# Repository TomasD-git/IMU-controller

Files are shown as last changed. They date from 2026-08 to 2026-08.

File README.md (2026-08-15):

# IMU controller  
### **Ultra low power IMU controller, can control anything over bluetooth using IMU, all running on coin cell CR2032 battery**  



## Features:  
- **Ultra low power 11.5uA power consumption in sleep mode**  
- **Most power consumption(LED on max brightness, cpu and ram fully active, BLE active, IMU running) 16.5mA**
- **Battery lasts 700ish days(11.1µA consumption on a 220mah battery)**
- **Powerfull BLE 5.3 with antenna**
- **NRF52810 as MCU**
- **BMI270 as IMU**
- **CR2032 battery**
- **Red LED**

<details>
<summary>How to does it work</summary>

## The button enables/disables the BLE  
## The LED indicates if BLE is active (LED flashes once = BLE on, LED flashes twice = BLE off)  
## All components are in deep sleep until accel detects movement  
## After few seconds of inactivity goes back to deep sleep  

</details>

<details>
<summary>How to flash</summary>

0. **Connect device to PC using segger j-link**   
1. **Open VS Code**  
2. **Select connected device in left bottom corner:** 


4. **Flash:**  
    

( For Debugging select: )  
  

</details>

<details>
<summary><strong>Power consumption</strong></summary>

## Deep Sleep:
| Component | What's active | Consumption |
|---|---|---|
| NRF52810 | Deep Sleep | 1.1µA |
| BMI270 | Accel-only Low power mode | 10µA |
| LED | Off | 0µA |
| Total | | 11.1µA |
| Battery life | 220,000µAh ÷ 11.1µA | ~825 days (~2.3 years) |
 
## Deep Sleep + slow BLE:
| Component | What's active | Consumption |
|---|---|---|
| NRF52810 | BLE with  4000ms interval (just to hold connections) | 6.4µA |
| BMI270 | Accel-only Low power mode | 10µA |
| LED | Off | 0µA |
| Total | | 16.4µA |
| Battery life | 220,000µAh ÷ 16.4µA | ~559 days (~1.53 years) |
 
## Fully active:
| Component | What's active | Consumption |
|---|---|---|
| NRF52810 | BLE with 7.5ms interval, CPU active | 13.8mA |
| BMI270 | Normal mode | 0.685mA |
| LED | On | 2.0mA |
| Total | | 16.485mA |
| Battery life | 220,000µAh ÷ 16.485mA | ~13.3 hours |

> **Can last less depending on quality of the Battery**  

</details>

<details>
<summary>How to Assemble</summary>

1. **Print all parts and assemble PCB**  
2. **Flash**  
3. **Place the Coin Cell battery into the holder**  
4. **Place the PCB inside the case**  
5. **Screw the bottom lid into the top one**  
6. **Verify it works by clicking the button**  

</details>

<details>  
<summary>Pictures</summary>  
  








</details>  

<details>
<summary>BOM</summary>

|Name |Purpose |Quantity  |Total Cost (USD)|Link |Distributor|
|---|---|---|---|---|---|
|PCB + stencil |all components are on this |1 |13.97 |https://jlcpcb.com |jlcpcb |
|ALL components|all components that are on pcb |1 |38.87 |https://lcsc.com |lcsc |
|CR2032 |battery which poweres the entire PCB |1 |4 | |local store|
|SEGGER J-Link |Flashes the NRF board with firmware |1 |4.94 |https://www.aliexpress.com/item/1005005802567589.html |Aliexpress |
|EU tarrifs |3 EU for each category for orders under 150 eu|3 |32.66 |https://commission.europa.eu/news-and-media/news/ensuring-fairness-and-safety-eur3-customs-duty-low-value-parcels-2026-06-29_en|EU |
| | |Total cost|94.44 | | |
| |If outside EU |Total cost|61.78 | | |

</details>

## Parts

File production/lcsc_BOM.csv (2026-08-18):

LCSC BOM.csv |  |  |  |  |  |  |  |  |  | LCSC BOM Quotation
 |  |  |  |  |  |  |  |  |  | BOM Date Created?18/08/26 19:02:04 |  |  |  | BOM Export Date: 18/08/26 19:03:08 |  |  |  | The matching result is a real-time query result, availability and prices may fluctuate. Backorder items are estimated prices for your reference, please submit "Create Quote" to get the real price. All information is provided "as is" and is subject to change without notice. Any use made of the information provided is without recourse to LCSC and at the user's risk.
 |  |  |  |  |  |  |  |  |  | EST TOTAL :$28.13 |  |  |  | Website?https://www.lcsc.com/bom
Uploaded data |  |  |  |  |  |  |  |  |  | LCSC Matching Results
LCSC# | Mfr. | Mrf# | Description | Package | Value | Customer Part Number | Quantity | Target Price(USD) | Target Lead Time(Business Days) | Mrf# | Mfr. | Order Qty. | Unit Price(USD) | Ext.Price(USD) | LCSC# | Package | Min | Mult | SPQ | Availability | Stock Status | Customer Notes | Description | Matched status | Product Link
C964833 |  |  | MY-2032-12 | BAT-SMD_MY-2032-12 |  | - | 5 |  |  | MY-2032-12 | MYOUNG | 5 | 0.0940 | 0.47 | C964833 | - | 5 | 5 | 1500 | 17040 | In Stock |  | Battery Clip Coin CR2032 Cell SMD | Exact Matches | https://www.lcsc.com/product-detail/C964833.html
C60474 |  |  | 100nF | 402 |  | - | 100 |  |  | CC0402KRX7R7BB104 | YAGEO | 100 | 0.0057 | 0.57 | C60474 | 0402 | 100 | 100 | 10000 | 4786700 | In Stock |  | 100nF ±10% 16V Ceramic Capacitor X7R 0402 | Exact Matches | https://www.lcsc.com/product-detail/C60474.html
C106201 |  |  | 12pF | 402 |  | - | 100 |  |  | CC0402JRNPO9BN120 | YAGEO | 100 | 0.0038 | 0.38 | C106201 | 0402 | 100 | 100 | 10000 | 1991400 | In Stock |  | 12pF ±5% 50V Ceramic Capacitor NP0 0402 | Exact Matches | https://www.lcsc.com/product-detail/C106201.html
C15850 |  |  | 10uF | 805 |  | - | 20 |  |  | CL21A106KAYNNNE | Samsung Electro-Mechanics | 20 | 0.0994 | 1.99 | C15850 | 0805 | 20 | 20 | 2000 | 3004120 | In Stock |  | 10uF ±10% 25V Ceramic Capacitor X5R 0805 | Exact Matches | https://www.lcsc.com/product-detail/C15850.html
C29936 |  |  | 0.8pF | 402 |  | - | 50 |  |  | CL10B105KA8NNNC | Samsung Electro-Mechanics | 50 | 0.0226 | 1.13 | C29936 | 0603 | 50 | 50 | 4000 | 2688800 | In Stock |  | 1uF ±10% 25V Ceramic Capacitor X7R 0603 | Exact Matches | https://www.lcsc.com/product-detail/C29936.html
C88902 |  |  | 4.7uF | 603 |  | - | 20 |  |  | GJM1555C1HR80WB01D | muRata | 20 | 0.0404 | 0.81 | C88902 | 0402 | 20 | 20 | 10000 | 187660 | In Stock |  | 0.8pF 50V Ceramic Capacitor C0G 0402 | Exact Matches | https://www.lcsc.com/product-detail/C88902.html
C19666 |  |  | 1.2pF | 402 |  | - | 10 |  |  | CL10A475KO8NNNC | Samsung Electro-Mechanics | 10 | 0.0336 | 0.34 | C19666 | 0603 | 10 | 10 | 4000 | 2943250 | In Stock |  | 4.7uF ±10% 16V Ceramic Capacitor X5R 0603 | Exact Matches | https://www.lcsc.com/product-detail/C19666.html
C1551 |  |  | 100pF | 402 |  | - | 100 |  |  | 0402CG1R2C500NT | FH | 100 | 0.0067 | 0.67 | C1551 | 0402 | 100 | 100 | 10000 | 262900 | In Stock |  | 1.2pF 50V Ceramic Capacitor C0G 0402 | Exact Matches | https://www.lcsc.com/product-detail/C1551.html
C26409 |  |  | 1uF | 603 |  | - | 100 |  |  | CL05C101JB5NNNC | Samsung Electro-Mechanics | 100 | 0.0075 | 0.75 | C26409 | 0402 | 100 | 100 | 10000 | 1025100 | In Stock |  | 100pF ±5% 50V Ceramic Capacitor C0G 0402 | Exact Matches | https://www.lcsc.com/product-detail/C26409.html
 |  |  | Conn_01x05 | PinSocket_1x05_P2.00mm_Vertical |  | - | 1 |  |  | - | - | - | - | - | - | - | - | - | - | - | - |  | - | No Matches Found
C98062 |  |  | 3.9nH | 402 |  | - | 20 |  |  | LQW15AN3N9B00D | muRata | 20 | 0.0391 | 0.78 | C98062 | 0402 | 20 | 20 | 10000 | 5760 | In Stock |  | 750mA 3.9nH 70m? Unshielded Inductor 0402 Fixed Inductors RoHS | Exact Matches | https://www.lcsc.com/product-detail/C98062.html
C2916136 |  |  | AN3216-245 | ANT-SMD_L3.2-W1.6-A |  | - | 5 |  |  | AN3216-245 | Rainsun | 5 | 0.1365 | 0.68 | C2916136 | 1206 | 5 | 5 | 3000 | 13935 | In Stock |  | nan | Exact Matches | https://www.lcsc.com/product-detail/C2916136.html
C91239 |  |  | 2.7nH | 402 |  | - | 20 |  |  | LQW15AN2N7B00D | muRata | 20 | 0.0644 | 1.29 | C91239 | 0402 | 20 | 20 | 10000 | 60920 | In Stock |  | 850mA 2.7nH 50m? Unshielded Inductor 0402 Fixed Inductors RoHS | Exact Matches | https://www.lcsc.com/product-detail/C91239.html
C86064 |  |  | 3.3nH | 402 |  | - | 50 |  |  | LQG15HS3N3S02D | muRata | 50 | 0.0195 | 0.98 | C86064 | 0402 | 50 | 50 | 10000 | 80100 | In Stock |  | 800mA 3.3nH 170m? Multilayer inductor 0402 Fixed Inductors RoHS | Exact Matches | https://www.lcsc.com/product-detail/C86064.html
C137695 |  |  | 620 | 603 |  | - | 100 |  |  | RC0603FR-07620RL | YAGEO | 100 | 0.0065 | 0.65 | C137695 | 0603 | 100 | 100 | 5000 | 123600 | In Stock |  | 620? 100mW 75V Thick Film Resistor ±100ppm/? ±1% 0603 Chip Resistor - Surface Mount RoHS | Exact Matches | https://www.lcsc.com/product-detail/C137695.html
C1558383 |  |  | NRF52810-QFAA-R | UQFN-48_L6.0-W6.0-P0.40-BL-EP4.6 |  | - | 2 |  |  | NRF52810-QFAA-T | NORDIC | 2 | 3.1247 | 6.25 | C1558383 | QFN-48-EP(6x6) | 1 | 1 | 490 | 243 | In Stock |  | IC RF TXRX 2400MHz~2483.5MHz QFN-48-EP(6x6) | Exact Matches | https://www.lcsc.com/product-detail/C1558383.html
C2848222 |  |  | FC31M2-32.768-N09LLDT | CRYSTAL-SMD_L3.2-W1.5 |  | - | 5 |  |  | FC31M2-32.768-N09LLDT | HCI | 5 | 0.2132 | 1.07 | C2848222 | SMD3215-2P | 5 | 5 | 3000 | 6345 | In Stock |  | Crystal 32.768kHz ±20ppm 9pF 50k? SMD3215-2P | Exact Matches | https://www.lcsc.com/product-detail/C2848222.html
C2836813 |  |  | BMI270 | LGA-14_L3.0-W2.5-P0.50-BR |  | - | 2 |  |  | BMI270 | Bosch | 2 | 3.4500 | 6.90 | C2836813 | LGA-14(2.5x3) | 1 | 1 | 5000 | 8040 | In Stock |  | LGA-14(2.5x3) IMUs (Inertial Measurement Units) RoHS | Exact Matches | https://www.lcsc.com/product-detail/C2836813.html
C7466002 |  |  | LS L29K-G1J2-1-Z | LED-SMD_L1.3-W0.8-LS1.7-FD |  | - | 1 |  |  | LS L29K-G1J2-1-Z | OSRAM | 5 | 0.2943 | 1.47 | C7466002 | 0603 | 5 | 5 | 5000 | 15275 | In Stock |  | Red 643nm LED Indication - Discrete 1.8V 0603 | Exact Matches | https://www.lcsc.com/product-detail/C7466002.html
C6630024 |  |  | PTS526SMG15SMTR21 LFS | SW-SMD_4P-L4.8-W4.8-P3.70-LS6.4-1 |  | - | 1 |  |  | PTS526SMG15SMTR21 LFS | C&K | 5 | 0.1176 | 0.59 | C6630024 | - | 5 | 5 | 4000 | 3075 | In Stock |  | Tactile Switches RoHS | Exact Matches | https://www.lcsc.com/product-detail/C6630024.html
C426985 |  |  | S3232000081040 | CRYSTAL-SMD_4P-L3.2-W2.5-BL |  | - | 1 |  |  | S3232000081040 | JGHC | 5 | 0.0715 | 0.36 | C426985 | SMD3225-4P | 5 | 5 | 3000 | 14095 | In Stock |  | Crystal 32MHz ±10ppm 8pF 40? SMD3225-4P | Exact Matches | https://www.lcsc.com/product-detail/C426985.html

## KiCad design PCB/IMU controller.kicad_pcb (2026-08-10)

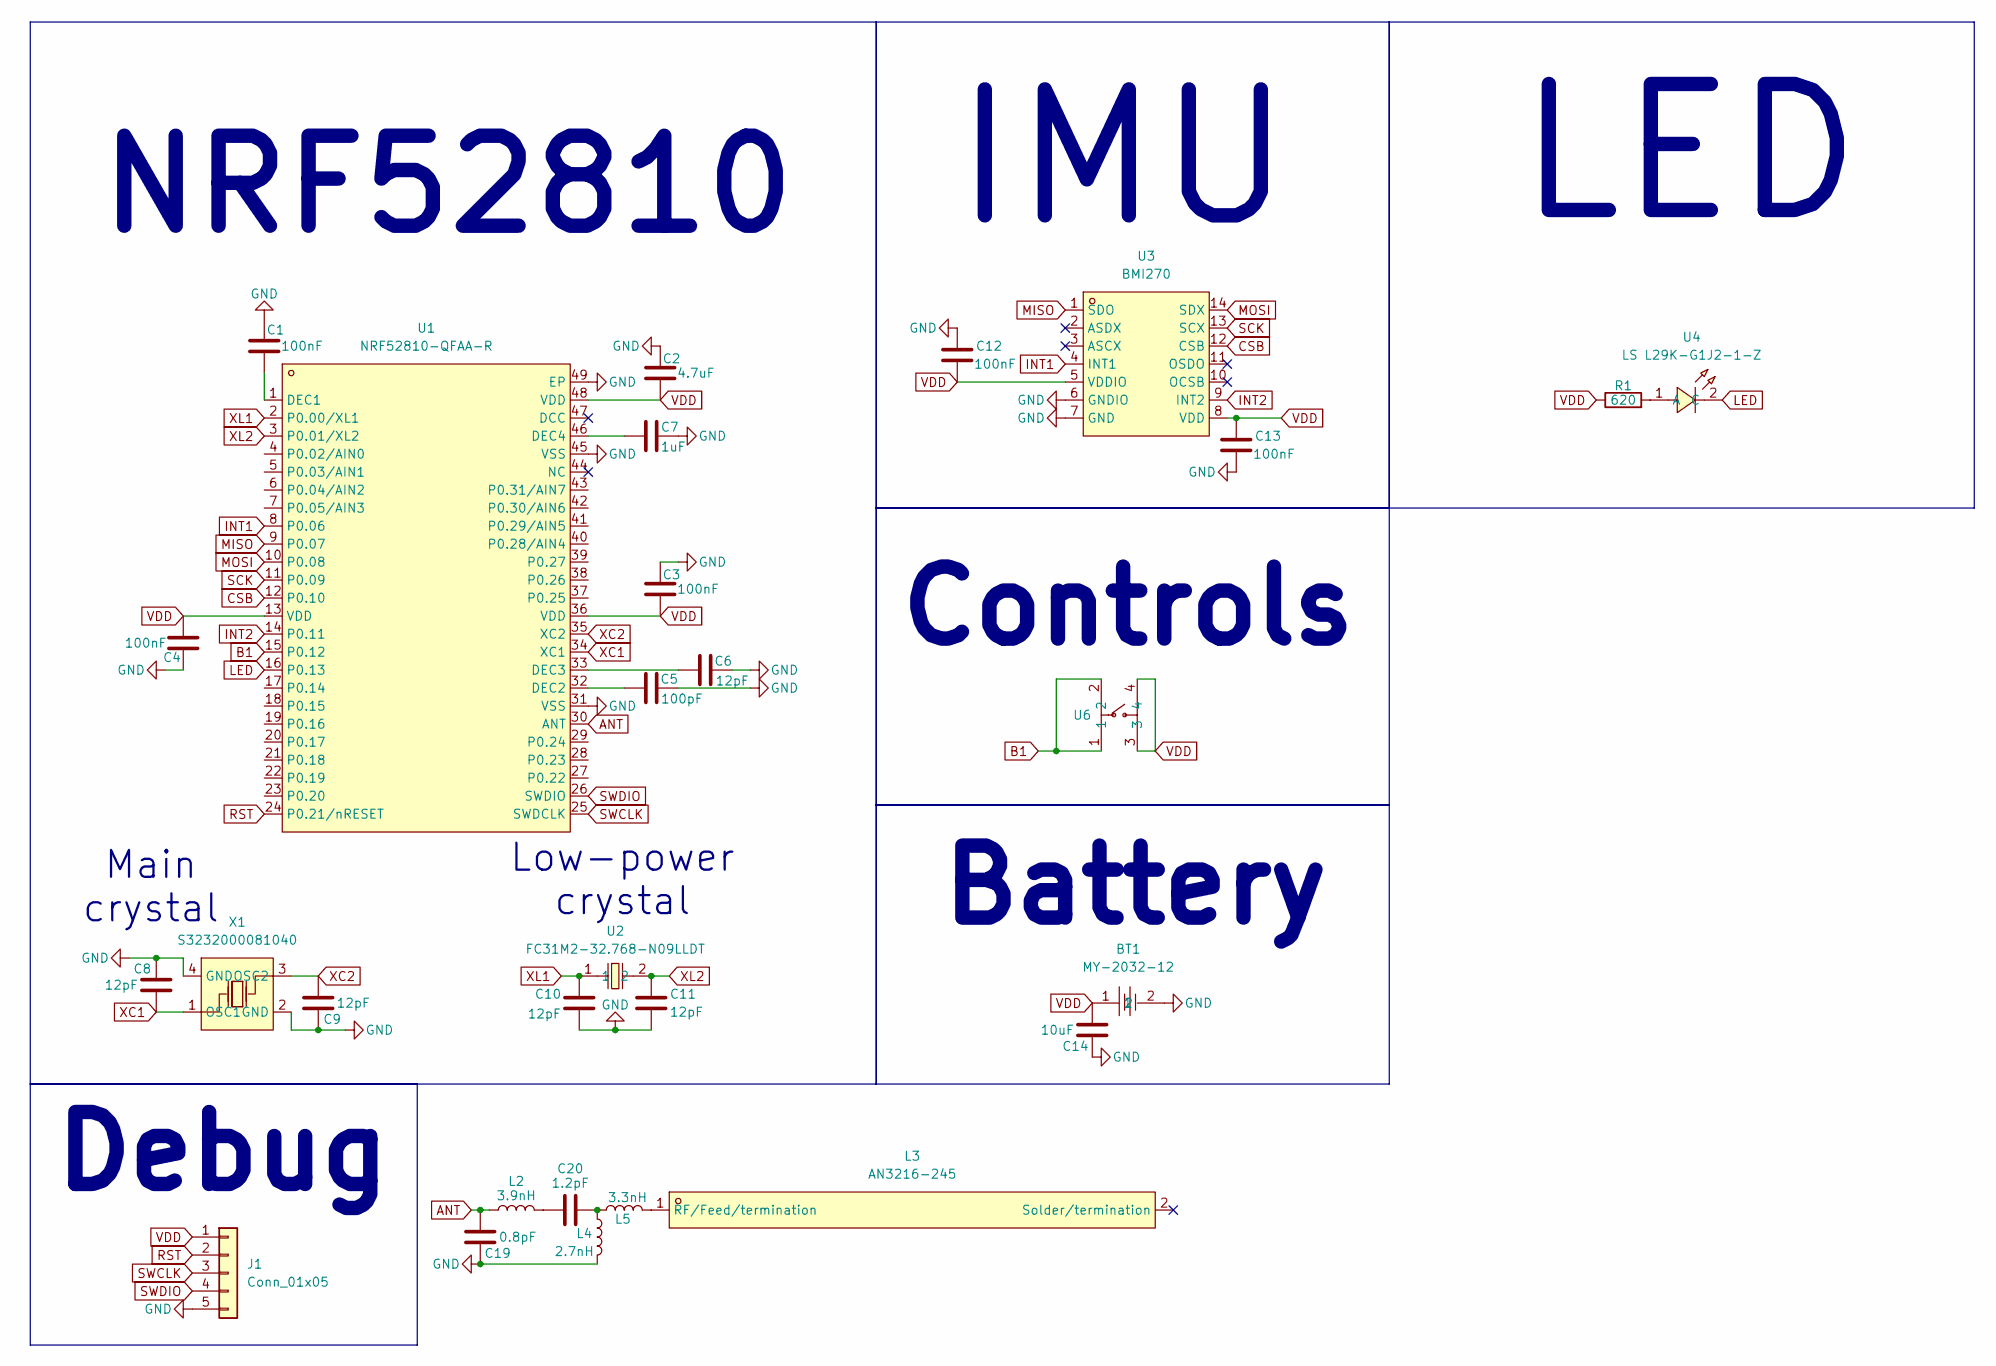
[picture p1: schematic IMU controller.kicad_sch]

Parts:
BT1: MY-2032-12; BAT-SMD_MY-2032-12; MPN MY-2032-12; LCSC Part C964833
C1, C3, C4, C12, C13: 100nF; C_0402_1005Metric
C2: 4.7uF; C_0603_1608Metric
C5: 100pF; C_0402_1005Metric
C6, C8, C9, C10, C11: 12pF; C_0402_1005Metric
C7: 1uF; C_0603_1608Metric
C14: 10uF; C_0805_2012Metric
C19: 0.8pF; C_0402_1005Metric
C20: 1.2pF; C_0402_1005Metric
J1: Conn_01x05; PinSocket_1x05_P2.00mm_Vertical
L2: 3.9nH; L_0402_1005Metric
L3: AN3216-245; ANT-SMD_L3.2-W1.6-A; MPN AN3216-245; LCSC Part C2916136
L4: 2.7nH; L_0402_1005Metric
L5: 3.3nH; L_0402_1005Metric
R1: 620; R_0603_1608Metric
U1: NRF52810-QFAA-R; UQFN-48_L6.0-W6.0-P0.40-BL-EP4.6; MPN NRF52810-QFAA-R; LCSC Part C141828
U2: FC31M2-32.768-N09LLDT; CRYSTAL-SMD_L3.2-W1.5; MPN FC31M2-32.768-N09LLDT; LCSC Part C2848222
U3: BMI270; LGA-14_L3.0-W2.5-P0.50-BR; MPN BMI270; LCSC Part C2836813
U4: LS L29K-G1J2-1-Z; LED-SMD_L1.3-W0.8-LS1.7-FD; MPN LS L29K-G1J2-1-Z; LCSC Part C7466002
U6: PTS526SMG15SMTR21 LFS; SW-SMD_4P-L4.8-W4.8-P3.70-LS6.4-1; MPN PTS526SMG15SMTR21 LFS; LCSC Part C6630024
X1: S3232000081040; CRYSTAL-SMD_4P-L3.2-W2.5-BL; MPN S3232000081040; LCSC Part C426985

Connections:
ANT: C19.1, L2.1, U1.30 (ANT)
B1: U1.15 (P0.12), U6.1, U6.2
CSB: U1.12 (P0.10), U3.12 (CSB)
GND: BT1.2, C1.1, C2.1, C3.1, C4.1, C5.2, C6.2, C7.1, C8.1, C9.1, C10.2, C11.2, C12.2, C13.1, C14.2, C19.2, J1.5, L4.2, U1.31 (VSS), U1.45 (VSS), U1.49 (EP), U3.6 (GNDIO), U3.7 (GND), X1.2 (GND), X1.4 (GND)
INT1: U1.8 (P0.06), U3.4 (INT1)
INT2: U1.14 (P0.11), U3.9 (INT2)
LED: U1.16 (P0.13), U4.2 (C)
MISO: U1.9 (P0.07), U3.1 (SDO)
MOSI: U1.10 (P0.08), U3.14 (SDX)
unnamed: C20.1, L2.2
unnamed: C20.2, L4.1, L5.1
unnamed: L3.1 (RF/Feed/termination), L5.2
unnamed: C1.2, U1.1 (DEC1)
unnamed: C5.1, U1.32 (DEC2)
unnamed: C6.1, U1.33 (DEC3)
unnamed: C7.2, U1.46 (DEC4)
unnamed: R1.2, U4.1 (A)
RST: J1.2, U1.24 (P0.21/nRESET)
SCK: U1.11 (P0.09), U3.13 (SCX)
SWCLK: J1.3, U1.25 (SWDCLK)
SWDIO: J1.4, U1.26 (SWDIO)
VDD: BT1.1, C2.2, C3.2, C4.2, C12.1, C13.2, C14.1, J1.1, R1.1, U1.13 (VDD), U1.36 (VDD), U1.48 (VDD), U3.5 (VDDIO), U3.8 (VDD), U6.3, U6.4
XC1: C8.2, U1.34 (XC1), X1.1 (OSC1)
XC2: C9.2, U1.35 (XC2), X1.3 (OSC2)
XL1: C10.1, U1.2 (P0.00/XL1), U2.1
XL2: C11.1, U1.3 (P0.01/XL2), U2.2

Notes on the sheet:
Battery
Low-power crystal
Controls
NRF52810
Main crystal
LED
IMU
Debug

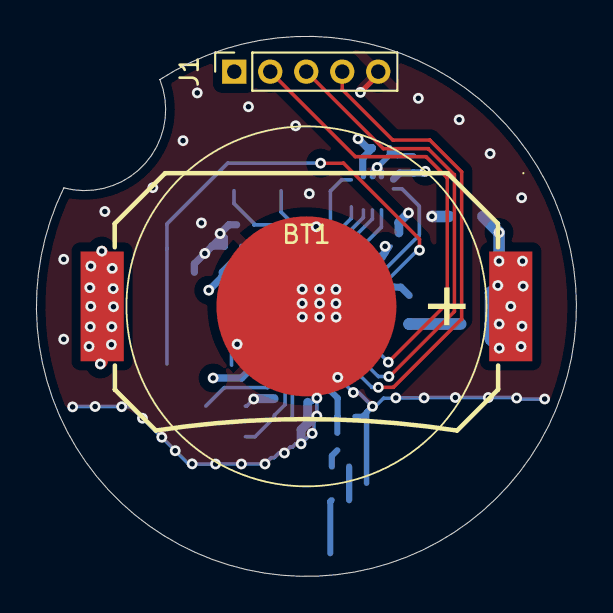
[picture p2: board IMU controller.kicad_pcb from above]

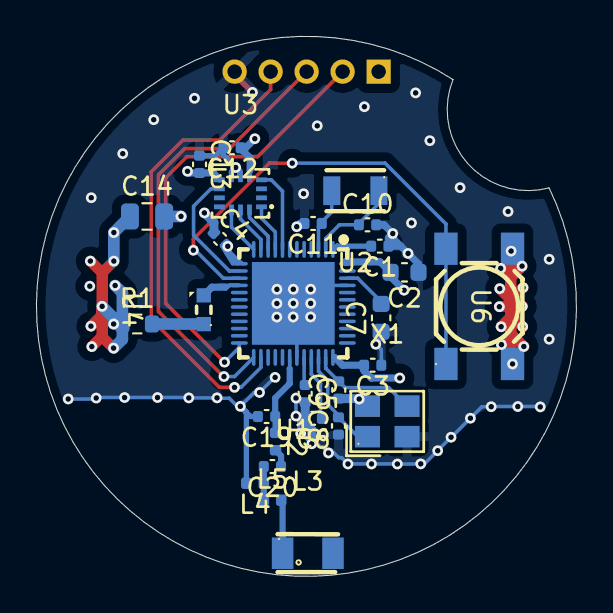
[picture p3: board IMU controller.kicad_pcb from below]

Board: 4 copper layers, 30.0 x 30.0 mm, 29 parts (27 on the bottom side), 26 nets.

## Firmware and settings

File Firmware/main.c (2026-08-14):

/**  IMU Controller  */
#include <zephyr/kernel.h>
#include <zephyr/device.h>
#include <zephyr/devicetree.h>
#include <zephyr/drivers/gpio.h>
#include <zephyr/drivers/sensor.h>
#include <zephyr/bluetooth/bluetooth.h>
#include <zephyr/bluetooth/conn.h>
#include <zephyr/bluetooth/gatt.h>
#include <zephyr/bluetooth/hci.h>
#include <zephyr/bluetooth/uuid.h>
#include <zephyr/logging/log.h>

LOG_MODULE_REGISTER(imu_controller, LOG_LEVEL_INF);

#define ROTATION_STEP_DEG          8.0f
#define ROTATION_POLL_INTERVAL_MS  20
#define INACTIVITY_TIMEOUT_MS      2000  
#define BUTTON_DEBOUNCE_MS         40
#define LED_BLINK_ON_MS            120
#define LED_BLINK_GAP_MS           120

static const struct gpio_dt_spec led    = GPIO_DT_SPEC_GET(DT_ALIAS(led0), gpios);
static const struct gpio_dt_spec button = GPIO_DT_SPEC_GET(DT_ALIAS(sw0), gpios);
static const struct device *bmi270_dev  = DEVICE_DT_GET(DT_NODELABEL(bmi270));

static struct gpio_callback button_cb_data;


static bool          m_ble_on   = false;
static float         m_accum_deg = 0.0f;
static struct bt_conn *m_conn   = NULL;
static bool           m_notify_enabled = false;

static void rotation_poll_work_handler(struct k_work *work);
static void inactivity_work_handler(struct k_work *work);
static void button_debounce_work_handler(struct k_work *work);
static void motion_trigger_work_handler(struct k_work *work);

K_WORK_DELAYABLE_DEFINE(rotation_poll_work, rotation_poll_work_handler);
K_WORK_DELAYABLE_DEFINE(inactivity_work, inactivity_work_handler);
K_WORK_DELAYABLE_DEFINE(button_debounce_work, button_debounce_work_handler);
K_WORK_DEFINE(motion_trigger_work, motion_trigger_work_handler);

static void led_on(void)  { gpio_pin_set_dt(&led, 1); }
static void led_off(void) { gpio_pin_set_dt(&led, 0); }

static void led_blink(uint8_t times)
{
    for (uint8_t i = 0; i < times; i++)
    {
        led_on();
        k_msleep(LED_BLINK_ON_MS);
        led_off();
        if (i + 1 < times)
        {
            k_msleep(LED_BLINK_GAP_MS);
        }
    }
}

static const uint8_t hid_report_map[] = {
    0x05, 0x0C,     
    0x09, 0x01,       
    0xA1, 0x01,      
    0x85, 0x01,      
    0x15, 0x00,    
    0x25, 0x01,       
    0x75, 0x01,   
    0x95, 0x02,      
    0x09, 0xE9,    
    0x09, 0xEA,      
    0x81, 0x02,     
    0x95, 0x01,     
    0x75, 0x06,      
    0x81, 0x01,      
    0xC0            
};

static uint8_t hid_info[] = { 0x11, 0x01, 0x00, 0x02 }; 
static uint8_t hid_report_ref[] = { 0x01, 0x01 };      
static uint8_t hid_ctrl_point;

static void hid_ccc_cfg_changed(const struct bt_gatt_attr *attr, uint16_t value)
{
    m_notify_enabled = (value == BT_GATT_CCC_NOTIFY);
    LOG_INF("HID notifications %s", m_notify_enabled ? "enabled" : "disabled");
}

static ssize_t read_hid_info(struct bt_conn *conn, const struct bt_gatt_attr *attr,
                              void *buf, uint16_t len, uint16_t offset)
{
    return bt_gatt_attr_read(conn, attr, buf, len, offset, hid_info, sizeof(hid_info));
}

static ssize_t read_report_map(struct bt_conn *conn, const struct bt_gatt_attr *attr,
                                void *buf, uint16_t len, uint16_t offset)
{
    return bt_gatt_attr_read(conn, attr, buf, len, offset, hid_report_map, sizeof(hid_report_map));
}

static ssize_t read_report(struct bt_conn *conn, const struct bt_gatt_attr *attr,
                            void *buf, uint16_t len, uint16_t offset)
{
    uint8_t idle = 0;
    return bt_gatt_attr_read(conn, attr, buf, len, offset, &idle, sizeof(idle));
}

static ssize_t write_ctrl_point(struct bt_conn *conn, const struct bt_gatt_attr *attr,
                                 const void *buf, uint16_t len, uint16_t offset, uint8_t flags)
{
    if (len == sizeof(hid_ctrl_point))
    {
        hid_ctrl_point = *((uint8_t *)buf);
    }
    return len;
}
BT_GATT_SERVICE_DEFINE(hid_svc,
    BT_GATT_PRIMARY_SERVICE(BT_UUID_HIDS),

    BT_GATT_CHARACTERISTIC(BT_UUID_HIDS_INFO, BT_GATT_CHRC_READ,
                            BT_GATT_PERM_READ, read_hid_info, NULL, NULL),

    BT_GATT_CHARACTERISTIC(BT_UUID_HIDS_REPORT_MAP, BT_GATT_CHRC_READ,
                            BT_GATT_PERM_READ, read_report_map, NULL, NULL),

    BT_GATT_CHARACTERISTIC(BT_UUID_HIDS_REPORT,
                            BT_GATT_CHRC_READ | BT_GATT_CHRC_NOTIFY,
                            BT_GATT_PERM_READ,
                            read_report, NULL, NULL),
    BT_GATT_CCC(hid_ccc_cfg_changed, BT_GATT_PERM_READ | BT_GATT_PERM_WRITE),
    BT_GATT_DESCRIPTOR(BT_UUID_HIDS_REPORT_REF, BT_GATT_PERM_READ,
                        NULL, NULL, hid_report_ref),

    BT_GATT_CHARACTERISTIC(BT_UUID_HIDS_CTRL_POINT,
                            BT_GATT_CHRC_WRITE_WITHOUT_RESP,
                            BT_GATT_PERM_WRITE, NULL, write_ctrl_point, NULL),
);

typedef enum { HID_VOLUME_UP, HID_VOLUME_DOWN } hid_key_t;

static void hid_send_key(hid_key_t key)
{
    if (!m_conn || !m_notify_enabled)
    {
        return;
    }
    uint8_t press = (key == HID_VOLUME_UP) ? 0x01 : 0x02;
    bt_gatt_notify(m_conn, &hid_svc.attrs[6], &press, sizeof(press));
    uint8_t release = 0;
    bt_gatt_notify(m_conn, &hid_svc.attrs[6], &release, sizeof(release));
}

static void connected(struct bt_conn *conn, uint8_t err)
{
    if (err)
    {
        LOG_WRN("Connection failed (err %u)", err);
        return;
    }
    m_conn = bt_conn_ref(conn);
    LOG_INF("Connected");
}

static void disconnected(struct bt_conn *conn, uint8_t reason)
{
    LOG_INF("Disconnected (reason %u)", reason);
    if (m_conn)
    {
        bt_conn_unref(m_conn);
        m_conn = NULL;
    }
    m_notify_enabled = false;
}

BT_CONN_CB_DEFINE(conn_callbacks) = {
    .connected = connected,
    .disconnected = disconnected,
};

static const struct bt_data adv_data[] = {
    BT_DATA_BYTES(BT_DATA_FLAGS, (BT_LE_AD_GENERAL | BT_LE_AD_NO_BREDR)),
    BT_DATA_BYTES(BT_DATA_UUID16_ALL, BT_UUID_16_ENCODE(BT_UUID_HIDS_VAL)),
    BT_DATA(BT_DATA_NAME_COMPLETE, CONFIG_BT_DEVICE_NAME, sizeof(CONFIG_BT_DEVICE_NAME) - 1),
};

static void motion_trigger_handler(const struct device *dev, const struct sensor_trigger *trig)
{
    k_work_submit(&motion_trigger_work);
}

static void motion_trigger_work_handler(struct k_work *work)
{
    if (!m_ble_on)
    {
        return; 
    }

    m_accum_deg = 0.0f;
    k_work_schedule(&rotation_poll_work, K_MSEC(ROTATION_POLL_INTERVAL_MS));
    k_work_reschedule(&inactivity_work, K_MSEC(INACTIVITY_TIMEOUT_MS));
}
static void rotation_poll_work_handler(struct k_work *work)
{
    if (!m_ble_on)
    {
        return;
    }
    struct sensor_value gyro[3];
    if (sensor_sample_fetch_chan(bmi270_dev, SENSOR_CHAN_GYRO_XYZ) == 0 &&
        sensor_channel_get(bmi270_dev, SENSOR_CHAN_GYRO_XYZ, gyro) == 0)
    {
        double dps = sensor_value_to_double(&gyro[2]) * (180.0 / 3.14159265358979);
        double dt_s = ROTATION_POLL_INTERVAL_MS / 1000.0;
        m_accum_deg += (float)(dps * dt_s);
        if (m_accum_deg >= ROTATION_STEP_DEG)
        {
            hid_send_key(HID_VOLUME_UP);
            m_accum_deg -= ROTATION_STEP_DEG;
            k_work_reschedule(&inactivity_work, K_MSEC(INACTIVITY_TIMEOUT_MS));
        }
        else if (m_accum_deg <= -ROTATION_STEP_DEG)
        {
            hid_send_key(HID_VOLUME_DOWN);
            m_accum_deg += ROTATION_STEP_DEG;
            k_work_reschedule(&inactivity_work, K_MSEC(INACTIVITY_TIMEOUT_MS));
        }
    }
    k_work_schedule(&rotation_poll_work, K_MSEC(ROTATION_POLL_INTERVAL_MS));
}

static void inactivity_work_handler(struct k_work *work)
{
    k_work_cancel_delayable(&rotation_poll_work);
}

static void ble_turn_on(void)
{
    m_ble_on = true;

    int err = bt_le_adv_start(BT_LE_ADV_CONN_FAST_1, adv_data, ARRAY_SIZE(adv_data), NULL, 0);
    if (err)
    {
        LOG_ERR("Advertising failed to start (err %d)", err);
    }

    led_blink(2);
}

static void ble_turn_off(void)
{
    m_ble_on = false;

    k_work_cancel_delayable(&rotation_poll_work);
    k_work_cancel_delayable(&inactivity_work);

    bt_le_adv_stop();
    if (m_conn)
    {
        bt_conn_disconnect(m_conn, BT_HCI_ERR_REMOTE_USER_TERM_CONN);
    }

    led_blink(1);
}


static void button_debounce_work_handler(struct k_work *work)
{
    if (gpio_pin_get_dt(&button) == 1) 
    {
        if (m_ble_on) { ble_turn_off(); }
        else          { ble_turn_on();  }
    }
}
static void button_pressed(const struct device *dev, struct gpio_callback *cb, uint32_t pins)
{
    k_work_schedule(&button_debounce_work, K_MSEC(BUTTON_DEBOUNCE_MS));
}

static int init_led(void)
{
    if (!gpio_is_ready_dt(&led)) { return -ENODEV; }
    return gpio_pin_configure_dt(&led, GPIO_OUTPUT_INACTIVE);
}
static int init_button(void)
{
    if (!gpio_is_ready_dt(&button)) { return -ENODEV; }

    int err = gpio_pin_configure_dt(&button, GPIO_INPUT);
    if (err) return err;

    err = gpio_pin_interrupt_configure_dt(&button, GPIO_INT_EDGE_RISING);
    if (err) return err;

    gpio_init_callback(&button_cb_data, button_pressed, BIT(button.pin));
    return gpio_add_callback(button.port, &button_cb_data);
}
static int init_imu(void)
{
    if (!device_is_ready(bmi270_dev))
    {
        LOG_ERR("BMI270 device not ready");
        return -ENODEV;
    }
    struct sensor_trigger trig = {
        .type = SENSOR_TRIG_MOTION,
        .chan = SENSOR_CHAN_ACCEL_XYZ,
    };
    return sensor_trigger_set(bmi270_dev, &trig, motion_trigger_handler);
}

int main(void)
{
    int err;

    err = init_led();
    if (err) { LOG_ERR("LED init failed (%d)", err); return err; }

    err = init_button();
    if (err) { LOG_ERR("Button init failed (%d)", err); return err; }

    err = bt_enable(NULL);
    if (err) { LOG_ERR("bt_enable failed (%d)", err); return err; }

    err = init_imu();
    if (err)
    {
        while (true)
        {
            led_on();  k_msleep(100);
            led_off(); k_msleep(100);
        }
    }
    return 0;
}

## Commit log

2026-08-09 Update battery description in README
2026-08-09 added KICAD pcb flies
    [IMU controller.kicad_pcb, IMU controller.kicad_sch]
2026-08-09 added production files
    [designators.csv, lcsc_bom.csv, positions.csv]
2026-08-09 added CAD files
2026-08-10 Update power consumption details in README
2026-08-10 added updated PCB files
    [IMU controller.kicad_pcb, IMU controller.kicad_sch]
2026-08-10 added BOM
    [BOM.csv]
2026-08-10 Add BOM section to README
    Added a BOM section with details on components, quantities, and costs.
2026-08-18 added updated lcsc bom
    [lcsc_BOM.csv]
